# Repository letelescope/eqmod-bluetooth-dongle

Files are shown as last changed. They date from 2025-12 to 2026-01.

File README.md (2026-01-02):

# DIY EQMOD Bluetooth Dongle

This project demonstrates how to set a wireless Bluetooth connection for an EQMOD-compatible telescope mount using an HC-05 Bluetooth module. Optionally, the HC-05 module can be configured using AT command mode, allowing you to customize its settings such as name, password, and baud rate.

> All this is very much inspired of the official EQDirect-BT schematic available on the [EQMod website](https://eq-mod.sourceforge.net/eqdirectindex.html).

## Project Structure

```markdown
eqmod-bluetooth-dongle/
├── electronics/                  # Circuit diagrams and PCB layouts (to be added)
│   ├── eqmod-bluetooth-dongle/   # PCB design files for the EQMOD Bluetooth dongle
│   └── README.md                 # Explains the schematics and PCB layouts
│
├── utils/
│   └── flash-HC-05/              # PlatformIO project to configure HC-05 via AT commands using an Arduino board
│       ├── src/
│       │   └── main.cpp          # Arduino firmware code for HC-05 configuration
│       ├── platformio.ini        # PlatformIO configuration file
│       └── README.md             # Usage of the HC-05 configuration utility
│ 
├── LICENSE                       # Project license
└── README.md                     # You are here!
```

For the time being, this project only includes the utility to configure the HC-05 module. The main EQMOD Bluetooth dongle firmware will be added in the future.

## Configuring HC-05 Module via AT Commands

For configuring the HC-05 module, you can use the provided PlatformIO project located in the [utils/flash-HC-05/](utils/flash-HC-05/) directory. This project allows you to send AT commands to the HC-05 module using an Arduino board as a bridge. Please see the [readme](utils/flash-HC-05/README.md) file in that directory for detailed instructions. 

But basically, to configure the HC-05 module, you can follow these steps:

1. Connect and wire the HC-05 module to your Arduino board
2. Upload the provided firmware to your Arduino board using PlatformIO.
3. Open the Serial Monitor and send AT commands to the HC-05 module.
4. The module will respond to the commands, allowing you to configure its settings.

## Electronics schematics

The schematic diagrams and PCB layouts for the EQMOD Bluetooth dongle can be found in the [electronics/eqmod-bluetooth-dongle/](electronics/eqmod-bluetooth-dongle/) directory. Please refer to the [readme](electronics/eqmod-bluetooth-dongle/README.md) file in that directory for detailed explanations of the schematics and PCB layouts.

### TL;DR:

The EQMOD Bluetooth dongle is designed around the HC-05 Bluetooth module, which provides wireless serial communication capabilities. The schematic includes the necessary connections for power, ground, and serial communication (TX/RX) between the HC-05 module and the mount. The design also incorporates level shifting components to ensure compatibility between the HC-05 module's voltage levels and the mount's logic levels.

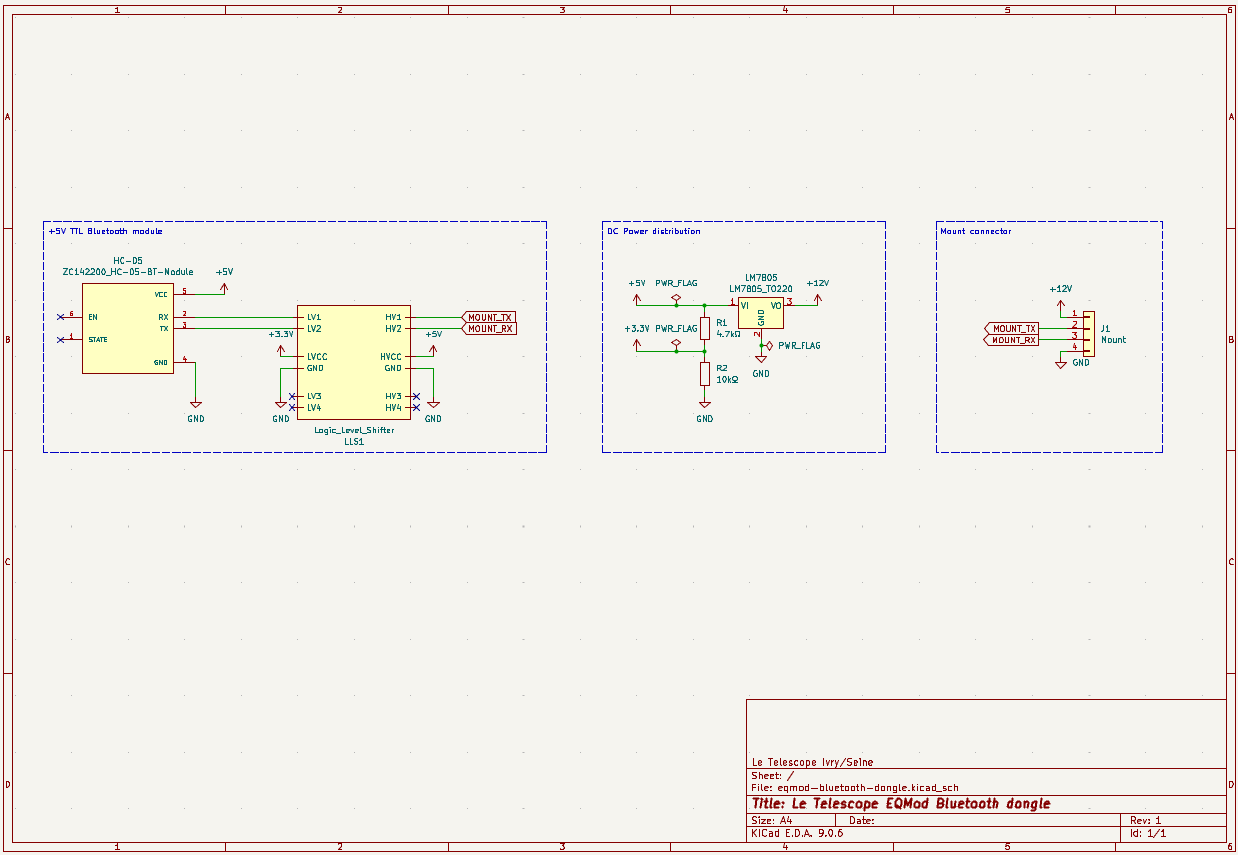
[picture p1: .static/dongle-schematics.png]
EQMOD Bluetooth Dongle Schematic


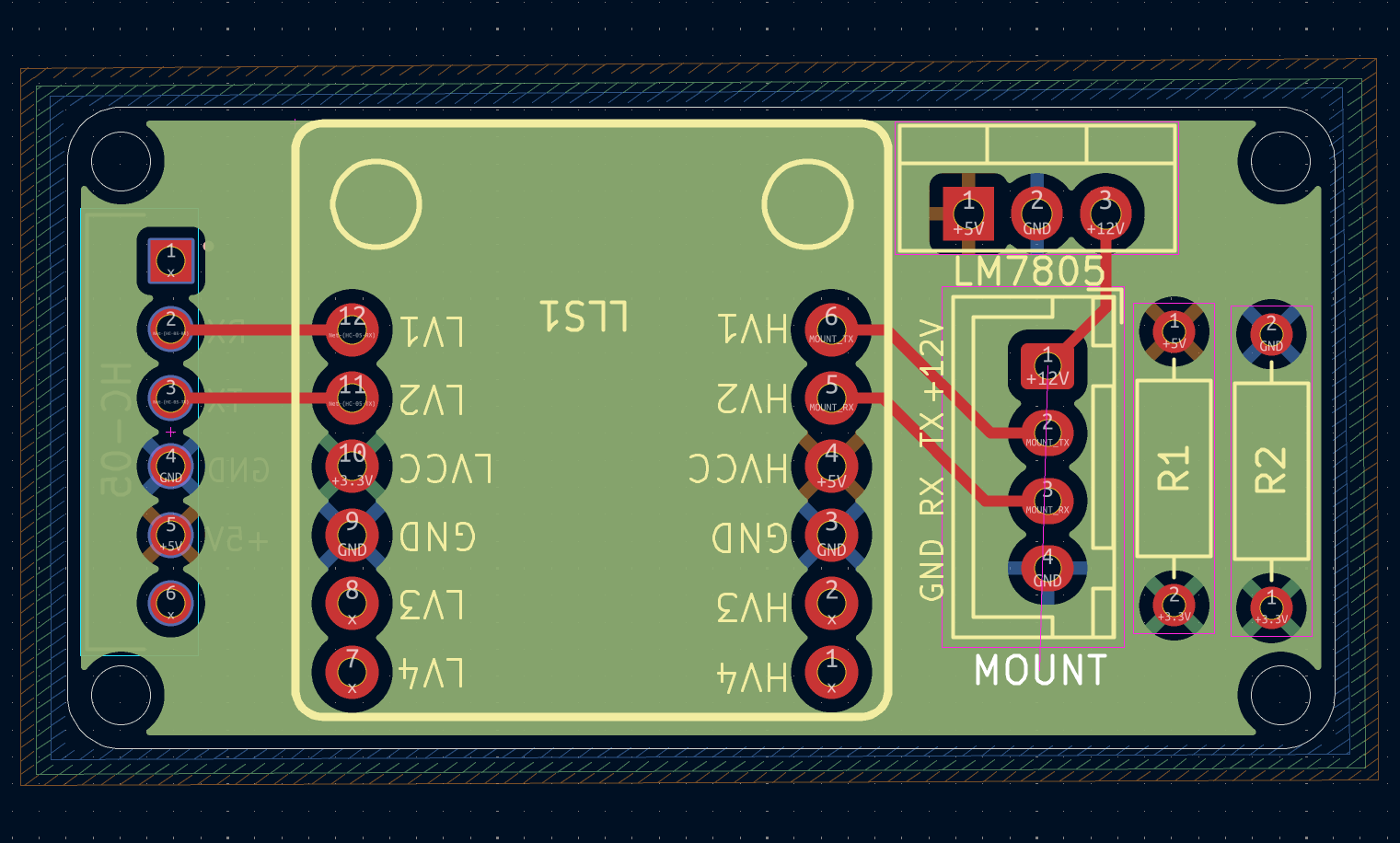
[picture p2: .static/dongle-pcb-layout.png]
EQMOD Bluetooth Dongle PCB


## Bibliography

- HC-05 Bluetooth Module Datasheet: [https://components101.com/sites/default/files/component_datasheet/HC-05%20Datasheet.pdf)](https://components101.com/sites/default/files/component_datasheet/HC-05%20Datasheet.pdf)
- EQMod EQDirect-BT documentation: [https://eq-mod.sourceforge.net/eqdirectindex.html](https://eq-mod.sourceforge.net/eqdirectindex.html)

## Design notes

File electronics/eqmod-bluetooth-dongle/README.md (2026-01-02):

# EQMOD Bluetooth Dongle - Electronics

Schematic diagrams and PCB layouts for the EQMOD Bluetooth dongle can be found in the [electronics/eqmod-bluetooth-dongle/](electronics/eqmod-bluetooth-dongle/) directory.

## Project Files

```markdown
electronics/eqmod-bluetooth-dongle/
├── footprints/                             # Electronic footprint files
├── eqmod-bluetooth-dongle.kicad_pro        # PCB project file
├── eqmod-bluetooth-dongle.kicad_sch        # Schematic file
├── eqmod-bluetooth-dongle.kicad_pcb        # PCB layout file
├── eqmod-bluetooth-dongle.kicad_prl        # PCB rules file
└──README.md                                # This file
```

## Schematic principles

> All this is very much inspired of the official EQDirect-BT schematic available on the [EQMod website](https://eq-mod.sourceforge.net/eqdirectindex.html).

The EQMOD Bluetooth dongle is designed around the HC-05 Bluetooth module, which provides wireless serial communication capabilities. The schematic includes the necessary connections for power, ground, and serial communication (TX/RX) between the HC-05 module and the mount. The design also incorporates level shifting components to ensure compatibility between the HC-05 module's voltage levels and the mount's logic levels.

EQMOD Bluetooth Dongle Schematic

It consist of three sections:

- The Bluetooth module section: The HC-05 module and the associated logic level shifter to enable +5V TTL signaling with the Mount.
- The Power section: This provides stable voltages
  - +5V from the +12V Mount power supply, using a LM7805 linear voltage regulator.
  - +3.3V from the +5V line, using a voltage divider.
- The mount connection section: A simple generic 4-pin connector to connect to the EQMOD-compatible mount (via wiring to RJ45, RJ12 or DB9 connectors).

## PCB Layout

The PCB design implements the schematic, adhering to a straightforward routing strategy. This is a 4-layer PCB:

- Top Layer: Component placement and signal routing. With the exception of +12V routing from mount connector to the voltage regulator.
- Inner Layer 1: +5V power plane.
- Inner Layer 2: +3.3V power plane.
- Bottom Layer: Ground plane.

EQMOD Bluetooth Dongle PCB

## Bibliography

- EQMod EQDirect-BT documentation: [https://eq-mod.sourceforge.net/eqdirectindex.html](https://eq-mod.sourceforge.net/eqdirectindex.html)

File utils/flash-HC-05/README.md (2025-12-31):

# Put HC-05 Bluetooth Module into AT Command Mode

This simple platformio project helps you put the HC-05 Bluetooth module into AT command mode. Once in AT command mode, you can configure various settings of the HC-05 module.

## Wiring

Connect the HC-05 module to your Arduino as follows:

- HC-05 VCC to Arduino 5V
- HC-05 GND to Arduino GND
- HC-05 TXD to Arduino RX (Pin 10). Optionally through logic level converter (to step up 3.3V to 5V)
- HC-05 RXD to Arduino TX (Pin 11) through logic level converter (to step down 5V to 3.3V)
- HC-05 KEY/EN to Arduino +3V3 to enter AT command mode

## Code

The following Arduino sketch sets up the HC-05 module in AT command mode and allows you to send AT commands via the Serial Monitor.

```cpp
#include <Arduino.h>
#include <SoftwareSerial.h>

const byte RX_PIN = 10; // RX arduino pin, connected (via logic level converter) to TX pin of the HC-05 bluetooth module
const byte TX_PIN = 11; // TX arduino pin, connected (via logic level converter) to RX pin of the HC-05 bluetooth module
const byte EN_PIN = 9;  // Directly connected to the enable pin of the HC-05 bluetooth module

SoftwareSerial Bluetooth(RX_PIN, TX_PIN); // RX, TX

void setup() {
  Serial.begin(9600);        // Arduino UNO default serial speed 

  selectBluetoothModuleMode(); // Prompt user to select mode AT command mode or Data mode
}

void loop() {

  if (Bluetooth.available()) {
    String command = Bluetooth.readStringUntil('\n');
    command.trim(); // Remove any trailing newline or spaces
    Serial.println(command); // Forward data from Bluetooth to Serial Monitor
  }

  if (Serial.available()) {
    String response = Serial.readStringUntil('\n');
    response.trim(); // Remove any trailing newline or spaces
    Bluetooth.println(response); // Forward data from Serial Monitor to Bluetooth
  }
}

// ...
```

This platformio project already includes the [main.cpp](./src/main.cpp) file as well as a [platformio.ini](./platformio.ini) file. Hence, you can directly upload it to your Arduino board and start palying with it.

## Usage

1. Upload the firmware to your Arduino board using platformio.
2. Open the Serial Monitor 
3. send AT commands to the HC-05 module. For example, you can type `AT` and press Enter. The module should respond with `OK`.

## Available AT Commands

Here are some common AT commands you can use with the HC-05 module:
- `AT`: Test command, should return `OK`
- `AT+VERSION?`: Query the firmware version of the module
- `AT+NAME?`: Query the current name of the module
- `AT+NAME=new_name`: Set a new name for the module
- `AT+PSWD?`: Query the current password
- `AT+PSWD=new_password`: Set a new password
- `AT+UART?`: Query the current baud rate
- `AT+UART=new_baud,0,0`: Set a new baud rate (e.g., `AT+UART=9600,0,0`)
- `AT+ROLE?`: Query the current role (master/slave)
- `AT+ROLE=0`: Set the module to slave mode
- `AT+ROLE=1`: Set the module to master mode
- `AT+ADDR?`: Query the MAC address of the module
- `AT+RESET`: Reset the module

## Notes

- Make sure the baud rate in the Serial Monitor is set to 9600.
- Ensure that the HC-05 module is powered correctly and the KEY/EN pin is set to HIGH before powering on the module to enter AT command mode.
- You may need to adjust the baud rate in the `Bluetooth.begin()` function if your HC-05 module is configured differently.
- Use a logic level converter to connect the RX and TX pins of the HC-05 module to the Arduino to avoid damaging the module.
- Refer to the HC-05 datasheet for a list of AT commands and their functions.
  
## License

This project is licensed under the MIT License - see the [LICENSE](../LICENSE) file for details.

## Bibliography

- [HC-05 Bluetooth Module Datasheet](https://components101.com/sites/default/files/component_datasheet/HC-05%20Datasheet.pdf
- PlatformIO Documentation: [https://platformio.org/](https://platformio.org/)
- Arduino SoftwareSerial Library: [https://www.arduino.cc/en/Reference/SoftwareSerial](https://docs.arduino.cc/learn/built-in-libraries/software-serial/)
- Chumbaka wiki entry: [Rename-the-HC05-Bluetooth-Module-Using-AT-Command](https://chumbaka.notion.site/HC05-Rename-the-HC05-Bluetooth-Module-Using-AT-Command-410d21d4d5864df1935bf5c9a5a42582)
- Hackster.io tutorial: [HC-05-bluetooth-module-with-arduino](https://www.hackster.io/Uniostar/hc-05-bluetooth-module-with-arduino-via-at-command-mode-b3595d)

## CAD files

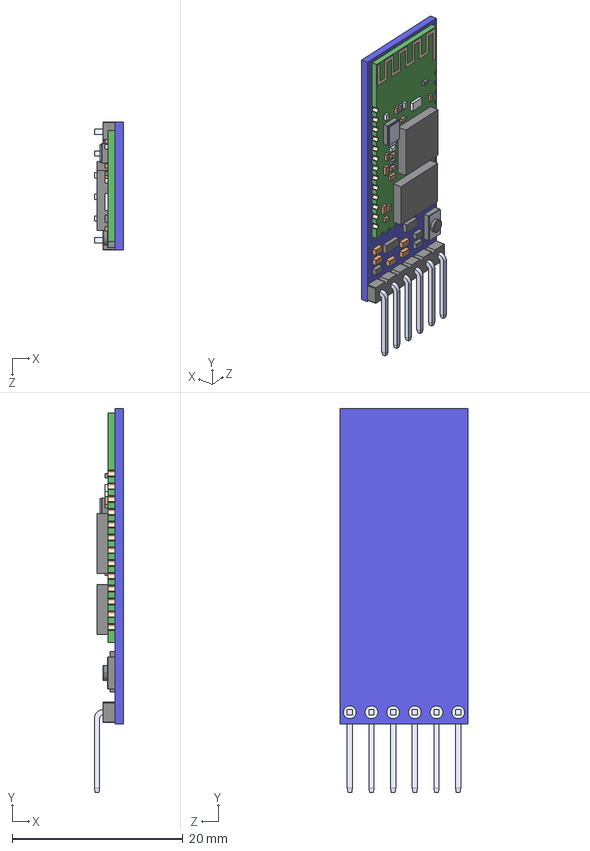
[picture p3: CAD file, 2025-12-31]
electronics/eqmod-bluetooth-dongle/footprints/ZC142200/ZC142200.step
3.41 x 45.0 x 15.0 mm
ZC142200
HC-05

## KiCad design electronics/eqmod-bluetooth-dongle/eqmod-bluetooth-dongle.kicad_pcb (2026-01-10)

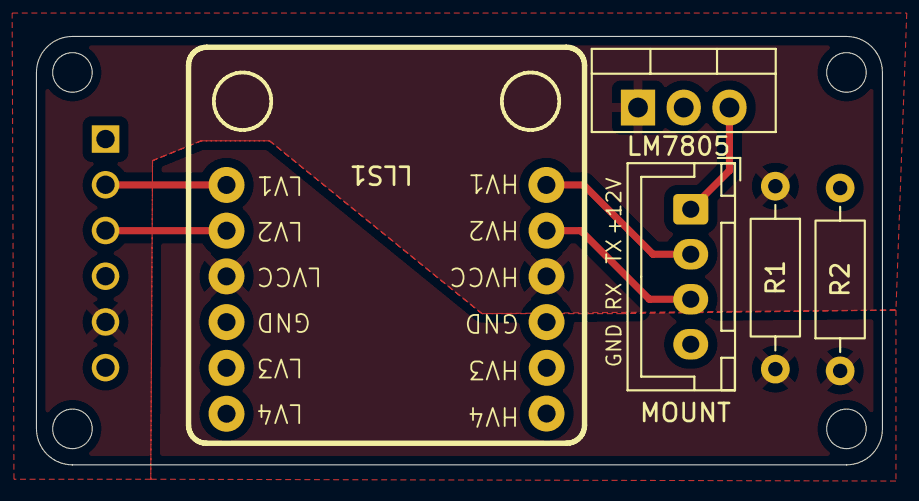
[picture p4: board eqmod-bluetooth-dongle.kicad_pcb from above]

Board: 2 copper layers, 47.0 x 23.8 mm, 6 parts (1 on the bottom side), 8 nets.

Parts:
HC-05: ZC142200_HC-05-BT-Module; MODULE_ZC142200_HC05
LLS1: Logic_Level_Shifter; 333029_Logic_Level_Shifter
LM7805: LM7805_TO220; TO-220-3_Vertical
MOUNT: Mount; JST_XH_B4B-XH-A_1x04_P2.50mm_Vertical
R1: 4.7kΩ; R_Axial_DIN0207_L6.3mm_D2.5mm_P10.16mm_Horizontal
R2: 10kΩ; R_Axial_DIN0207_L6.3mm_D2.5mm_P10.16mm_Horizontal

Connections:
+3.3V: LLS1.10 (LVCC), R1.2, R2.1
+5V: HC-05.5 (VCC), LLS1.4 (HVCC), LM7805.1 (VI), R1.1
+12V: LM7805.3 (VO), MOUNT.1
GND: HC-05.4 (GND), LLS1.3 (GND), LLS1.9 (GND), LM7805.2 (GND), MOUNT.4, R2.2
MOUNT_RX: LLS1.5 (HV2), MOUNT.3
MOUNT_TX: LLS1.6 (HV1), MOUNT.2
unnamed: HC-05.2 (RX), LLS1.12 (LV1)
unnamed: HC-05.3 (TX), LLS1.11 (LV2)

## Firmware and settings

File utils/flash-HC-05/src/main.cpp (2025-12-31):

/*
 * main.cpp
 * Copyright (C) 2025 - Present, Le Télescope - Ivry sur Seine - All Rights Reserved
 * Licensed under the MIT License. See the accompanying LICENSE file for terms.
 *
 * Description: Arduino firmware to configure the HC-05 module.
 *
 * Authors:
 * - Florian Gautier
 *
 */
#include <Arduino.h>
#include <SoftwareSerial.h>

const byte RX_PIN = 10; // RX arduino pin, connected (via logic level converter) to TX pin of the HC-05 bluetooth module
const byte TX_PIN = 11; // TX arduino pin, connected (via logic level converter) to RX pin of the HC-05 bluetooth module

SoftwareSerial Bluetooth(RX_PIN, TX_PIN); // RX, TX

int selectBluetoothModuleMode();

void setup() {

  Serial.begin(9600);          // Arduino UNO default serial speed 

  selectBluetoothModuleMode(); // Prompt user to select mode AT command mode or Data mode
}

void loop() {

  if (Bluetooth.available()) {
    String command = Bluetooth.readStringUntil('\n');
    command.trim(); // Remove any trailing newline or spaces
    Serial.println(command); // Forward data from Bluetooth to Serial Monitor
  }

  if (Serial.available()) {
    String response = Serial.readStringUntil('\n');
    response.trim(); // Remove any trailing newline or spaces
    Bluetooth.println(response); // Forward data from Serial Monitor to Bluetooth
  }
}

int selectBluetoothModuleMode() {
  Serial.println("Select HC-05 Bluetooth Module Mode:");
  Serial.println("1: AT Command Mode, ensure KEY/EN pin is HIGH before powering the module.");
  Serial.println("2: Data Mode, ensure KEY/EN pin is LOW before powering the module.");

  while (true) {
    if (Serial.available()) {
      switch (Serial.readStringUntil('\n').toInt())
      {
      case 1:
        Serial.println("HC-05 set to AT Command Mode.");
        Bluetooth.begin(38400); // Default baud rate for AT command mode
        return 1;
      case 2:
        Serial.println("HC-05 set to Data Mode.");
        Bluetooth.begin(9600); // Default baud rate for Data mode
        return 2;
      default:
        Serial.println("Invalid choice. Please enter 1 or 2:");
        break;
      }
    }
  }
}

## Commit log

2025-12-30 fix: HC-05 flash util is not properly working (#1)
    * Read and write a line at a time
    * Switch between AT and data mode
    [main.cpp]
2025-12-31 feat: Kicad project init (#2)
    * Kicad project initialization
    * First schematics draft
    * Schematics documentation
    * Minor util fimware changes
    [ZC142200.step, eqmod-bluetooth-dongle.kicad_pcb, eqmod-bluetooth-dongle.kicad_sch]
2026-01-02 feat: Initiate PCB layout (#3)
    * Init PCB layout
    * With power planes
    * With markings
    * Documenting PCB layout
    * First test ready
    [eqmod-bluetooth-dongle.kicad_pcb, eqmod-bluetooth-dongle.kicad_sch]
2026-01-02 feat: 4-layer PCB (#4)
    * 4-layer PCB routing
    * Documentation update
    [eqmod-bluetooth-dongle.kicad_pcb]
2026-01-02 feat: standard JST connector (#5)
    * Change mount connector to standard JST connector
    [eqmod-bluetooth-dongle.kicad_pcb, eqmod-bluetooth-dongle.kicad_sch]
2026-01-05 Fix: Use connector that can be sourced from supplier (#6)
    [eqmod-bluetooth-dongle.kicad_pcb, eqmod-bluetooth-dongle.kicad_sch]
2026-01-10 Let's go print some PCB (#7)
    [eqmod-bluetooth-dongle.kicad_pcb]
